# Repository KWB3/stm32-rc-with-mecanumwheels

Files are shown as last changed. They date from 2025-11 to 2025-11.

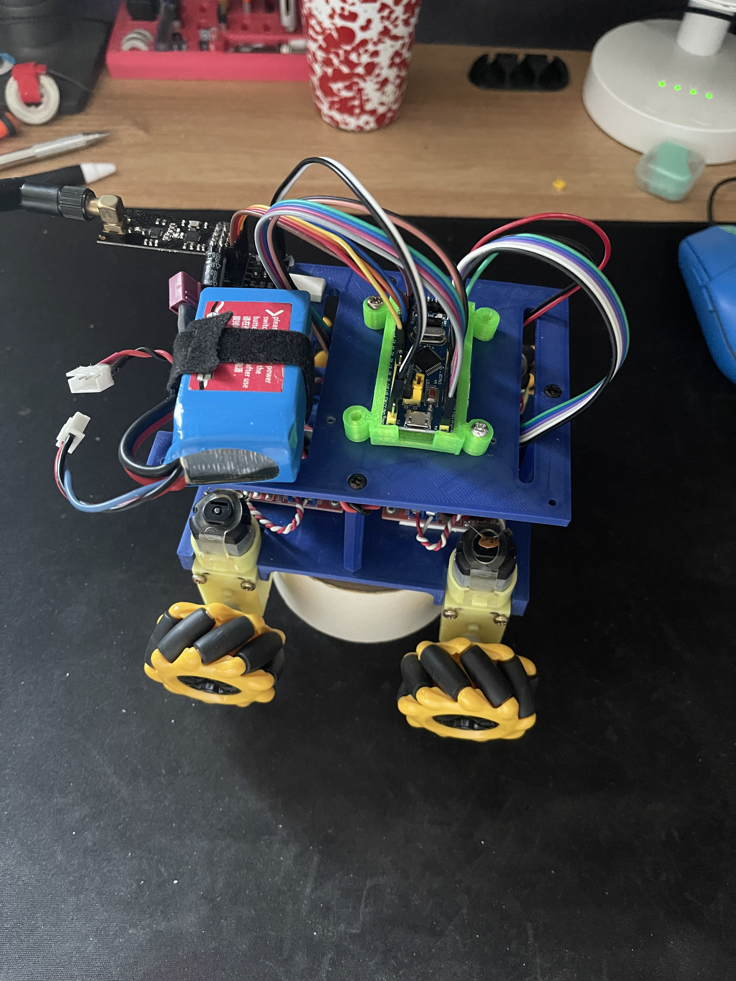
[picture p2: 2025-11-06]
rc mecanumwheel 01.jpeg

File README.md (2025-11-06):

# stm32-rc-with-mecanumwheels
Mecanumwheel RC Car (with STM32F103 & NRF24L01P)

STM32F103C8T6 - 메카넘휠 RC카입니다.  
NRF24L01P모듈이 수신한 데이터로 DC모터 4개를 제어하여 전/후진, 회전, 측면 이동을 구현

----------------------------------------------------------------------------------

기능 요약
- NRF24L01P 무선 모듈을 통한 데이터 수신
- L298N 모터 드라이버로 DC기어박스 모터 제어
- 메카넘휠을 이용한 다방향 이동 (전/후진, 좌/우 이동, 회전)
- 디버깅 및 테스트를 위한 시리얼 출력 지원
- 모터 속도 제어를 위한 PWM 신호 사용
- 간단한 체크섬을 통한 데이터 무결성 확인

----------------------------------------------------------------------------------

사용 부품 / 모듈 목록

- STM32F103C8T6 (Blue Pill) x1 - 메인 MCU
- NRF24L01P 무선 모듈 x1 - 데이터 수신
- L298N 모터 드라이버 x2 - DC모터 제어 
- DC 기어박스 모터 x4 - 메카넘휠 구동
- 메카넘휠 세트 x1 - 이동 구현
- 세라믹 캐패시터 0.1uf x4 - 모터 노이즈 필터링
- 전해 캐패시터 10uf x1 - nrf24 안정화
- 점퍼 케이블, 브레드보드 등 - 배선 및 연결
- 2s LiPo 배터리 팩 x1 - 전원 공급

----------------------------------------------------------------------------------
개발 환경

- IDE: STM32CubeIDE
- MCU: STM32F103C8T6
- Language: C

https://youtube.com/shorts/Do_-FFipm78

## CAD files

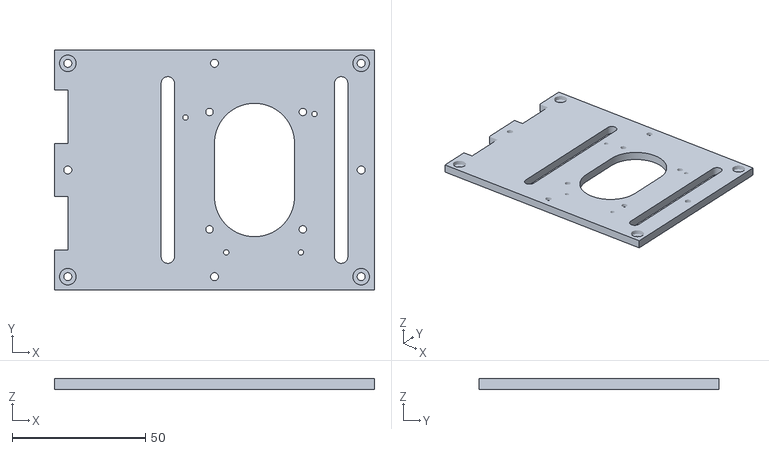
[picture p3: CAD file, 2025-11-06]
stl_files/rc_main_body2.stl
120.0 x 90.0 x 4.00

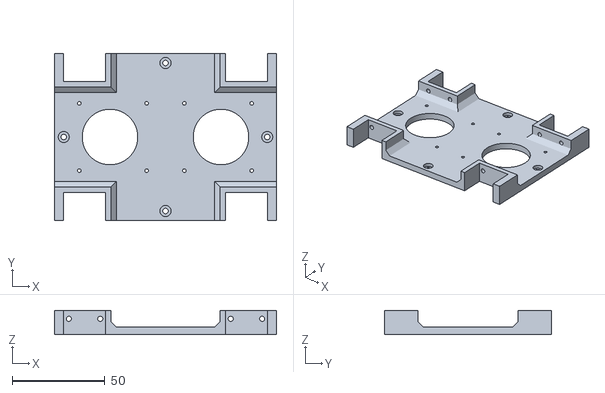
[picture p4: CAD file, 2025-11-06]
stl_files/rc_main_body1.stl
120.0 x 90.0 x 13.0

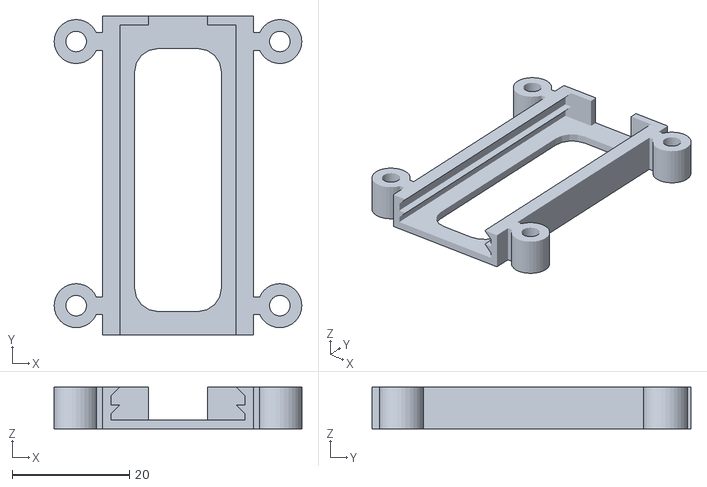
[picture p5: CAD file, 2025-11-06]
stl_files/pcbholder.stl
42.2 x 54.4 x 7.15

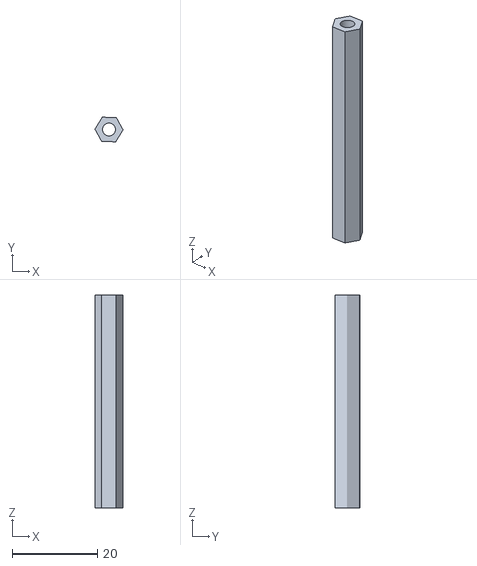
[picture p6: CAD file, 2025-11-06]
stl_files/supporter_M3_50mm.stl
6.60 x 5.78 x 50.0

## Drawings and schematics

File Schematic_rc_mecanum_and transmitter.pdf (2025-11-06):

L298N

L298N

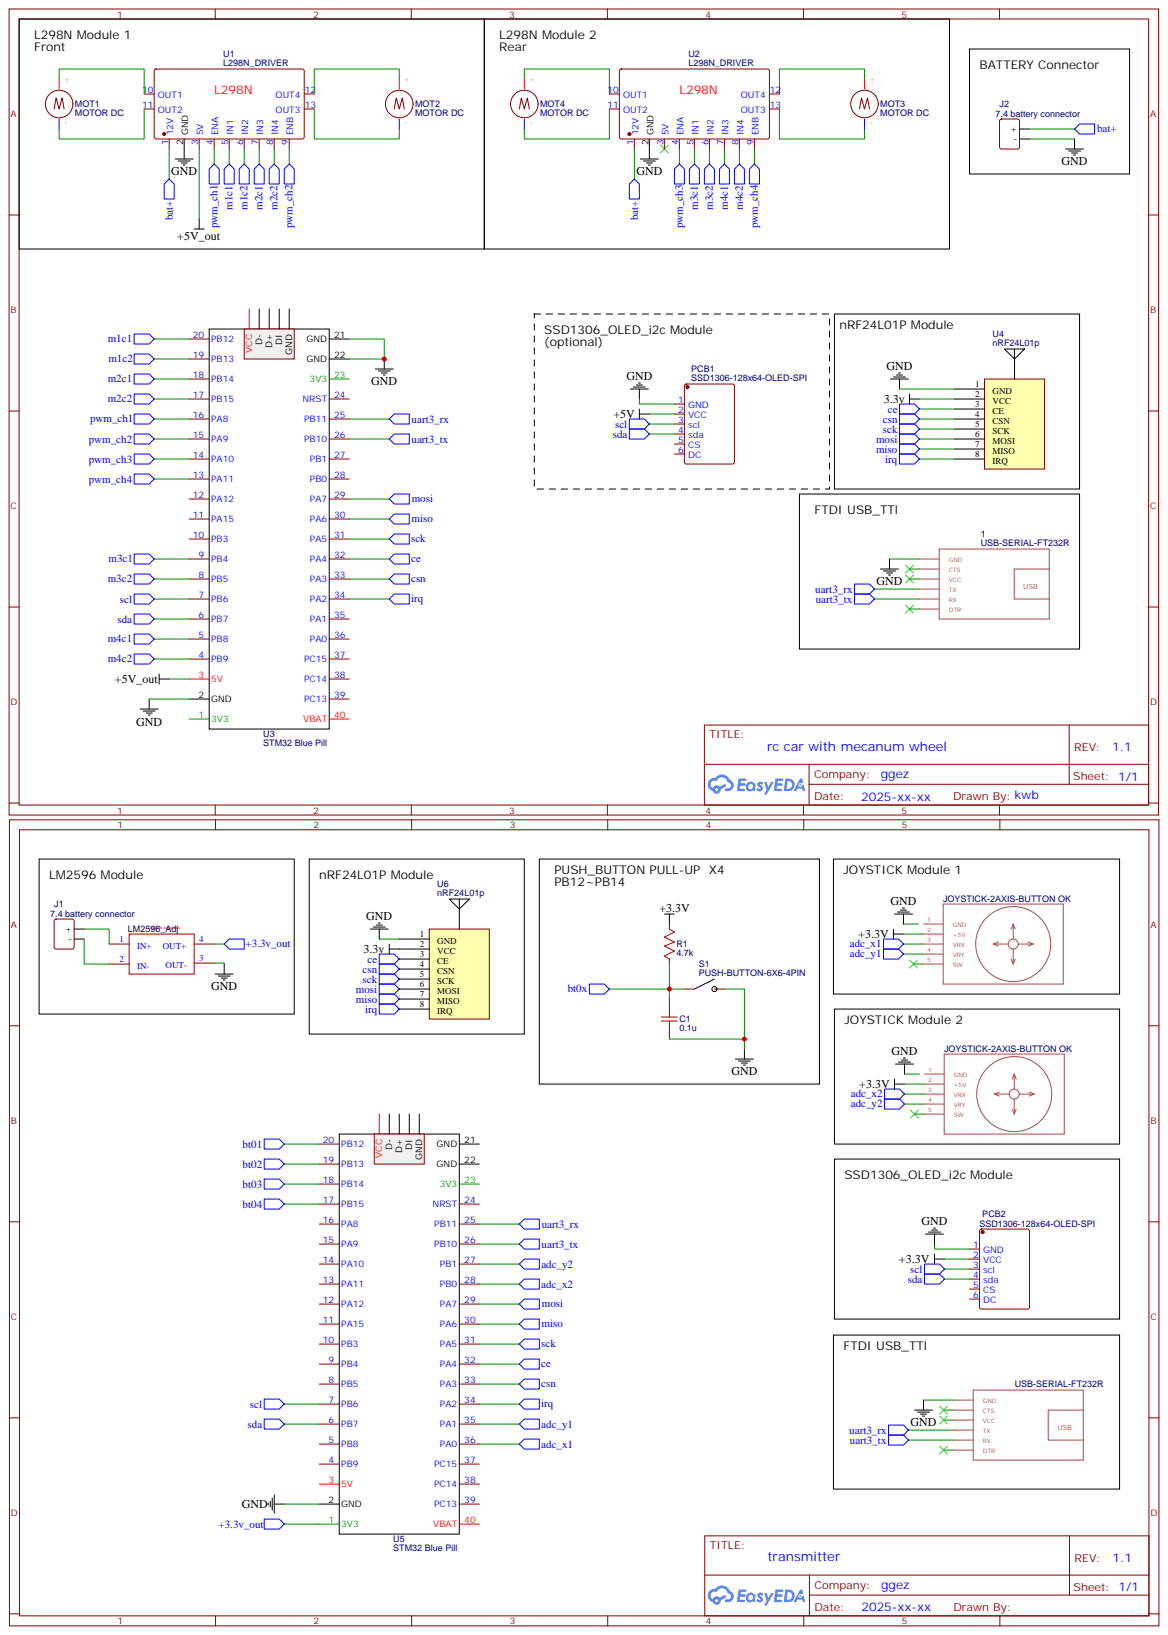
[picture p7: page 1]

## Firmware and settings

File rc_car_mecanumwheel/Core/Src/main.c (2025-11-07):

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
/* Includes ------------------------------------------------------------------*/
#include "main.h"
#include "i2c.h"
#include "spi.h"
#include "tim.h"
#include "usart.h"
#include "gpio.h"

/* USER CODE BEGIN Includes */
#include "nrf24l01p.h"
#include <stdio.h>
/* USER CODE END Includes */

/* USER CODE BEGIN PTD */
//#define uart_test					// UART 테스트용 정의, 주석제거시 활성화 uart3 사용
#define RX_BUFFER_SIZE 100
/* USER CODE END PTD */


/* USER CODE BEGIN PV */
/*
Byte0   : 0xAB            // HEADER (시작 마커)
Byte1   : seq             // 시퀀스 번호 (0..255)
Byte2   : joy0_x  	  	// 좌스틱 X (0..255)
Byte3   : joy0_y   		// 좌스틱 Y (0..255)
Byte4   : joy1_x 	 	 // 우스틱 X (0..255)
Byte5   : joy1_y 	 	// 우스틱 Y (0..255)
Byte6   : btn_flags (u8)  // 버튼 비트맵: bit0..3=버튼1..4,
Byte7   : checksum (u8)   // simple checksum (예: sum of bytes1..6) & 0xFF
Byte8   : 0xBA            // TAIL (끝 마커)
 */
#ifdef uart_test
uint8_t rx_data;                // 1바이트 수신 버퍼
uint8_t rx_buffer[RX_BUFFER_SIZE]; // 수신 문자열 버퍼
uint16_t rx_index = 0;
uint8_t rxx_text[RX_BUFFER_SIZE]; // 수신 문자열 버퍼
#endif

uint8_t rxx_data[NRF24L01P_PAYLOAD_LENGTH] = {127,127,127,127,127,127,127,127,127};
uint8_t rx_flag;

typedef enum {
	PACKET_OK = 0,           // 정상 패킷
	PACKET_INVALID_HEADER,   // 헤더가 잘못됨
	PACKET_INVALID_TAIL,     // 테일이 잘못됨
	PACKET_INVALID_CS,      // checksum 잘못됨
} PacketStatus_t;
/* USER CODE END PV */

void SystemClock_Config(void);
static void MX_NVIC_Init(void);
/* USER CODE BEGIN PFP */
int _write(int file, char *ptr, int len)
{
	HAL_UART_Transmit(&huart3, (uint8_t *)ptr, len, HAL_MAX_DELAY);

	return len;
}
#ifdef uart_test
void HAL_UART_RxCpltCallback(UART_HandleTypeDef *huart)
{
	if (huart->Instance == USART3)
	{
		if (rx_data == '\n' || rx_data == '\r')
		{
			rx_buffer[rx_index] = '\0'; // 문자열 종료

			// 에코 출력
			printf("%s\r\n", rx_buffer);
			rx_index = 0; // 인덱스 초기화
		}
		else
		{
			if (rx_index < RX_BUFFER_SIZE - 1)
			{
				rx_buffer[rx_index++] = rx_data;
			}
		}

		// 다음 바이트 수신 대기
		HAL_UART_Receive_IT(&huart3, &rx_data, 1);
	}
}
#endif

PacketStatus_t checkPackit()
{
	if(rxx_data[0] != 0xAB)
	{
		return PACKET_INVALID_HEADER;
	}

	if(rxx_data[8] != 0xBA)
	{
		return PACKET_INVALID_TAIL;
	}

	if(((rxx_data[1] + rxx_data[2] + rxx_data[3]+ rxx_data[4]+ rxx_data[5] + rxx_data[6]) & 0xFF) != rxx_data[7])
	{
		return PACKET_INVALID_CS;
	}

	return PACKET_OK;
}

void lf_backward()
{
	HAL_GPIO_WritePin(m1c1_GPIO_Port, m1c1_Pin, 1);
	HAL_GPIO_WritePin(m1c2_GPIO_Port, m1c2_Pin, 0);
}

void lf_forward()
{
	HAL_GPIO_WritePin(m1c1_GPIO_Port, m1c1_Pin, 0);
	HAL_GPIO_WritePin(m1c2_GPIO_Port, m1c2_Pin, 1);
}

void rf_forward()
{
	HAL_GPIO_WritePin(m2c1_GPIO_Port, m2c1_Pin, 1);
	HAL_GPIO_WritePin(m2c2_GPIO_Port, m2c2_Pin, 0);
}

void rf_backward()
{
	HAL_GPIO_WritePin(m2c1_GPIO_Port, m2c1_Pin, 0);
	HAL_GPIO_WritePin(m2c2_GPIO_Port, m2c2_Pin, 1);
}

void lr_forward()
{
	HAL_GPIO_WritePin(m3c1_GPIO_Port, m3c1_Pin, 1);
	HAL_GPIO_WritePin(m3c2_GPIO_Port, m3c2_Pin, 0);
}

void lr_backward()
{
	HAL_GPIO_WritePin(m3c1_GPIO_Port, m3c1_Pin, 0);
	HAL_GPIO_WritePin(m3c2_GPIO_Port, m3c2_Pin, 1);
}

void rr_backward()
{
	HAL_GPIO_WritePin(m4c1_GPIO_Port, m4c1_Pin, 1);
	HAL_GPIO_WritePin(m4c2_GPIO_Port, m4c2_Pin, 0);
}

void rr_forward()
{
	HAL_GPIO_WritePin(m4c1_GPIO_Port, m4c1_Pin, 0);
	HAL_GPIO_WritePin(m4c2_GPIO_Port, m4c2_Pin, 1);
}
void brake()
{
	HAL_GPIO_WritePin(m1c1_GPIO_Port, m1c1_Pin, 1);
	HAL_GPIO_WritePin(m1c2_GPIO_Port, m1c2_Pin, 1);
	HAL_GPIO_WritePin(m2c1_GPIO_Port, m2c1_Pin, 1);
	HAL_GPIO_WritePin(m2c2_GPIO_Port, m2c2_Pin, 1);
	HAL_GPIO_WritePin(m3c1_GPIO_Port, m3c1_Pin, 1);
	HAL_GPIO_WritePin(m3c2_GPIO_Port, m3c2_Pin, 1);
	HAL_GPIO_WritePin(m4c1_GPIO_Port, m4c1_Pin, 1);
	HAL_GPIO_WritePin(m4c2_GPIO_Port, m4c2_Pin, 1);
	TIM1->CCR1 = 0;
	TIM1->CCR2 = 0;
	TIM1->CCR3 = 0;
	TIM1->CCR4 = 0;
}
/*
 * Numbers represent each direction
 *										<roller direction>
 *           7   8   9			      (lf)  \\\		///  (rf)
 *           4  body 6						    body
 *           1   2   3				  (lr)	///		\\\  (rr)
 *
 * Each direction describes the direction of rotation of the motor.
 * Check the roller direction of the Mecanum wheel.
 * lf - left front(pwm1), rf - right front(pwm2), lr - left rear(pwm3), rr - right rear(pwm4)
 *
 *       9 - lf, rr motors rotate forward
 *       8 - All motors rotate forward
 *       7 - rf, lr motors rotate forward
 *       6 - lf, rr motors rotate forward, rf, lr motors rotate backward
 *       4 - rf, lr motors rotate forward, lf, rr motors rotate backward
 *       3 - rf, lr motors rotate backward
 *       2 - All motors rotate backward
 *       1 - lf, rr motors rotate backward
 */
void direction9(uint8_t ccr)
{
	lf_forward();
	rr_forward();
	TIM1->CCR1 = ccr;
	TIM1->CCR2 =  0;
	TIM1->CCR3 =  0;
	TIM1->CCR4 =  ccr;
}

void direction8(uint8_t ccr)
{
	lf_forward();
	rr_forward();
	rf_forward();
	lr_forward();
	TIM1->CCR1 =  ccr;
	TIM1->CCR2 =  ccr;
	TIM1->CCR3 =  ccr;
	TIM1->CCR4 =  ccr;
}

void direction7(uint8_t ccr)
{
	rf_forward();
	lr_forward();
	TIM1->CCR1 = 0;
	TIM1->CCR2 = ccr;
	TIM1->CCR3 = ccr;
	TIM1->CCR4 = 0;
}

void direction6(uint8_t ccr)
{
	rf_backward();
	lr_backward();
	lf_forward();
	rr_forward();
	TIM1->CCR1 =  ccr;
	TIM1->CCR2 =  ccr;
	TIM1->CCR3 =  ccr;
	TIM1->CCR4 =  ccr;
}

void direction4(uint8_t ccr)
{
	rf_forward();
	lr_forward();
	lf_backward();
	rr_backward();
	TIM1->CCR1 =  ccr;
	TIM1->CCR2 =  ccr;
	TIM1->CCR3 =  ccr;
	TIM1->CCR4 =  ccr;
}

void direction3(uint8_t ccr)
{
	rf_backward();
	lr_backward();
	TIM1->CCR1 = 0;
	TIM1->CCR2 = ccr;
	TIM1->CCR3 = ccr;
	TIM1->CCR4 = 0;
}

void direction2(uint8_t ccr)
{
	lf_backward();
	lr_backward();
	rr_backward();
	rf_backward();
	TIM1->CCR1 = ccr;
	TIM1->CCR2 = ccr;
	TIM1->CCR3 = ccr;
	TIM1->CCR4 = ccr;
}

void direction1(uint8_t ccr)
{
	lf_backward();
	rr_backward();
	TIM1->CCR1 = ccr;
	TIM1->CCR2 = 0;
	TIM1->CCR3 = 0;
	TIM1->CCR4 = ccr;
}

void turnLeft()
{
	lf_backward();
	lr_backward();
	rf_forward();
	rr_forward();
	TIM1->CCR1 = 100;
	TIM1->CCR2 = 100;
	TIM1->CCR3 = 100;
	TIM1->CCR4 = 100;
}

void turnRight()
{
	lf_forward();
	lr_forward();
	rf_backward();
	rr_backward();
	TIM1->CCR1 = 100;
	TIM1->CCR2 = 100;
	TIM1->CCR3 = 100;
	TIM1->CCR4 = 100;
}
/* USER CODE END PFP */

/**
 * @brief  The application entry point.
 * @retval int
 */
int main(void)
{

	/* MCU Configuration--------------------------------------------------------*/

	/* Reset of all peripherals, Initializes the Flash interface and the Systick. */
	HAL_Init();

	/* Configure the system clock */
	SystemClock_Config();

	/* Initialize all configured peripherals */
	MX_GPIO_Init();
	MX_I2C1_Init();
	MX_SPI1_Init();
	MX_TIM1_Init();
	MX_USART3_UART_Init();

	/* Initialize interrupts */
	MX_NVIC_Init();
	/* USER CODE BEGIN 2 */

	nrf24l01p_rx_init(2500, _1Mbps);
	HAL_TIM_PWM_Start(&htim1, TIM_CHANNEL_1);
	HAL_TIM_PWM_Start(&htim1, TIM_CHANNEL_2);
	HAL_TIM_PWM_Start(&htim1, TIM_CHANNEL_3);
	HAL_TIM_PWM_Start(&htim1, TIM_CHANNEL_4);
#ifdef uart_test
	HAL_UART_Receive_IT(&huart3, &rx_data, 1);
#endif
	/* USER CODE END 2 */

	/* Infinite loop */
	/* USER CODE BEGIN WHILE */


	while (1)
	{

		if((rx_flag == 1) && (checkPackit() == PACKET_OK))
		{
			if(rxx_data[6] & 0x01) //bt1 pushed
			{
				turnLeft();
			}
			else if(rxx_data[6] & 0x02) //bt2 pushed
			{
				turnRight();
			}
			else if(rxx_data[3] > 135)
			{
				direction8(rxx_data[3]-127);
			}
			else if(rxx_data[3] < 120)
			{
				direction2(127 - rxx_data[3]);
			}
			else if(rxx_data[2] > 135)
			{
				direction4(rxx_data[2]-127);
			}
			else if(rxx_data[2] < 120)
			{
				direction6(127 - rxx_data[2]);
			}
			else if(rxx_data[4] > 135)
			{
				direction7(rxx_data[4]-127);
			}
			else if(rxx_data[4] < 120)
			{
				direction3(127 - rxx_data[4]);
			}
			else if(rxx_data[5] > 135)
			{
				direction9(rxx_data[5]-127);
			}
			else if(rxx_data[5] < 120)
			{
				direction1(127 - rxx_data[5]);
			}
			else
			{
				brake();
			}

			rx_flag = 0;
		}

		/* USER CODE END WHILE */

		/* USER CODE BEGIN 3 */
	}
	/* USER CODE END 3 */
}

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
/* USER CODE BEGIN 4 */
void HAL_GPIO_EXTI_Callback(uint16_t GPIO_Pin)
{
	if(GPIO_Pin == NRF24L01P_IRQ_PIN_NUMBER)
	{
		rx_flag = 1;
		nrf24l01p_rx_receive(rxx_data);
#ifdef uart_test
		sprintf(rxx_text, "%02x, %02x, %02x, %02x, %02x, %02x, %02x, %02x, %02x\r\n", rxx_data[0], rxx_data[1], rxx_data[2], rxx_data[3], rxx_data[4], rxx_data[5], rxx_data[6], rxx_data[7], rxx_data[8]);
		HAL_UART_Transmit(&huart3, rxx_text, RX_BUFFER_SIZE, HAL_MAX_DELAY);
#endif
	}

}
/* USER CODE END 4 */
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


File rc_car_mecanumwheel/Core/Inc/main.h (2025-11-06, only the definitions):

#define irq_Pin GPIO_PIN_2
#define irq_GPIO_Port GPIOA
#define irq_EXTI_IRQn EXTI2_IRQn
#define csn_Pin GPIO_PIN_3
#define csn_GPIO_Port GPIOA
#define ce_Pin GPIO_PIN_4
#define ce_GPIO_Port GPIOA
#define m1c1_Pin GPIO_PIN_12
#define m1c1_GPIO_Port GPIOB
#define m1c2_Pin GPIO_PIN_13
#define m1c2_GPIO_Port GPIOB
#define m2c1_Pin GPIO_PIN_14
#define m2c1_GPIO_Port GPIOB
#define m2c2_Pin GPIO_PIN_15
#define m2c2_GPIO_Port GPIOB
#define m3c1_Pin GPIO_PIN_4
#define m3c1_GPIO_Port GPIOB
#define m3c2_Pin GPIO_PIN_5
#define m3c2_GPIO_Port GPIOB
#define m4c1_Pin GPIO_PIN_8
#define m4c1_GPIO_Port GPIOB
#define m4c2_Pin GPIO_PIN_9
#define m4c2_GPIO_Port GPIOB

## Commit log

2025-11-06 all files
    all files
    [rc_main_body1.stl, rc_main_body2.stl, supporter_M3_50mm.stl]
2025-11-06 Edit and add files
    Edit and add files
    [pcbholder.stl, rc_main_body2.stl]

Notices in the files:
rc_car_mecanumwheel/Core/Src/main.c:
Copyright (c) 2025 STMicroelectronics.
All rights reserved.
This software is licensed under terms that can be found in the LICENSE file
